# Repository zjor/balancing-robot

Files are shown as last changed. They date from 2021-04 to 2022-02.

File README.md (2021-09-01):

# Self-balancing robot

BLE-controlled self-balancing robot

- [Android BLE Joystick](/android/serial-ble-rc)
- [Arduino Code](/nano/twbr-nano)

## BOM

- Keywish BLE Nano x1
- A4988 Stepper Driver x2
- Stepper motor Nema17 x2
- MPU6050 x1

## References

- [Hackaday](https://hackaday.io/project/180126-self-balancing-robot-for-humans/)
- [Arduino Project](https://create.arduino.cc/projecthub/zjor/self-balancing-robot-with-arduino-nano-and-steppers-9bf019)
- Youtube (https://youtu.be/_VPTOirKccM)
- [Habr](https://habr.com/ru/post/575662/)

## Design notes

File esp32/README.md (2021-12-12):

# Self-balancing robot with ESP32 WROOM

## Pinout

### LED Wiring

- RED: GPIO32
- GREEN: GPIO33
- BLUE: GPIO25

### MPU9250 Wiring

- SCL: GPIO22
- SDA: GPIO21
- INT: GPIO19

### Motor 1 Wiring

- EN: GPIO15
- DIR: GPIO14
- STEP: GPIO12

### Motor 2 Wiring

- EN: GPIO16
- DIR: GPIO26
- STEP: GPIO27

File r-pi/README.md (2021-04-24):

# Balancing Robot

## Configuring headless Pi

1. Connect SD card to USB
2. `touch ssh` in the root directory
3. Create `wpa_supplicant.conf` file in the root directory with the following content

```
country=CZ
ctrl_interface=DIR=/var/run/wpa_supplicant GROUP=netdev
update_config=1
 
network={
    ssid="SSID"
    psk="PASSWORD"
}

```

4. Plug SD card to Pi and boot, after some time connect using
- `ssh pi@raspberrypi.local`

default password: raspberry

## Shutting down R Pi

`sudo shutdown -h now`

## Enable I2C

1. Install dependencies
```
sudo apt-get install -y python-smbus
sudo apt-get install -y i2c-tools
```

2. Enable I2C support
`sudo raspi-config`

3. Test connected devices
`sudo i2cdetect -y 1`

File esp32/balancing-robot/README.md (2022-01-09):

# Balancing Robot ESP32 WROOM

## Patching `SparkFun MPU-9250 Digital Motion Processing _DMP_ Arduino Library`

1. Go to `src/util/inv_mpu.h`
2. Add the following lines:
```C
#define min(X,Y) (((X) < (Y)) ? (X) : (Y))
#define max(X,Y) (((X) > (Y)) ? (X) : (Y))
```

## Notes

- `roll` is used for balancing

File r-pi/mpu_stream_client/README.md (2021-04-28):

# MPU Stream Client

- Renders a 3D object
- Pitch and roll are controlled by MPU data received via UPD stream

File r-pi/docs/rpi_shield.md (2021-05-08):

# R Pi Shield Spec

## PIN mapping

- MOT1_DIR -> GPIO_6 (31)
- MOT1_STEP -> GPIO_5 (29)
- MOT2_DIR -> GPIO_27 (13)
- MOT2_STEP -> GPIO_17 (11)
- MPU_SCL -> GPIO_3 (5)
- MPU_SDA -> GPIO_2 (3)

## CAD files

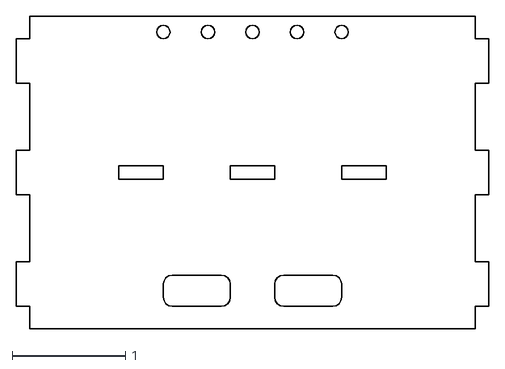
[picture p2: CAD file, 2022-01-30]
drawings/v3/bottom.dxf
4.17 x 2.76

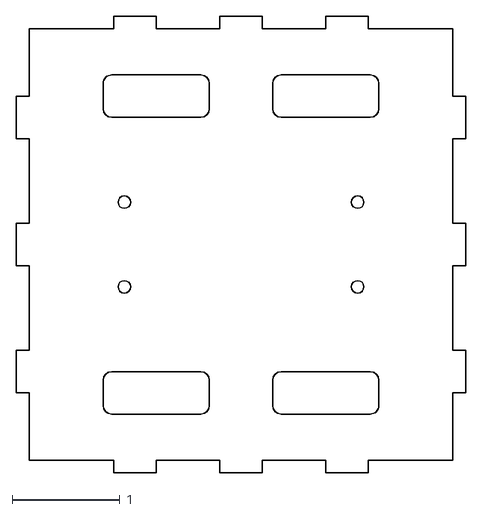
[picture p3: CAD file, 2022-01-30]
drawings/v3/middle.dxf
4.17 x 4.24

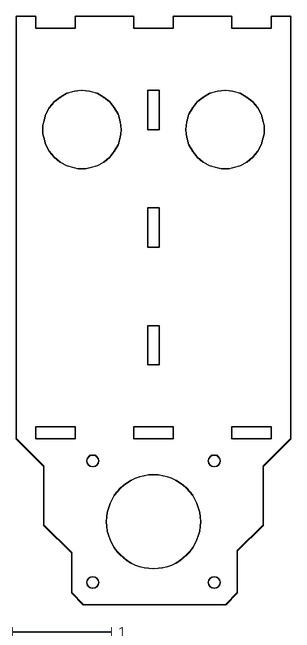
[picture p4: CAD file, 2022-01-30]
drawings/v3/side.dxf
2.76 x 5.91

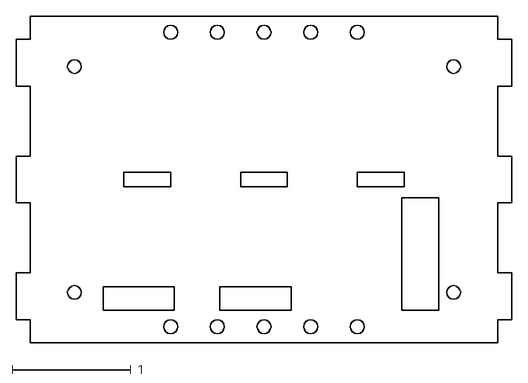
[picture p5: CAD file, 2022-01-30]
drawings/v3/top-mount.dxf
4.17 x 2.76

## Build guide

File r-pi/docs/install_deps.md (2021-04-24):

## Fixing "ImportError: No module named RPi"
- `sudo apt-get update`
- `sudo apt-get install python3-dev python3-rpi.gpio`

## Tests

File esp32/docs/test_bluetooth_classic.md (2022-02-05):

# Test Bluetooth classic sketch

ESP32 supports both BLE and Bluetooth classic protocol.
Bluetooth classic will be used to control the robot via serial protocol.

```
#include "BluetoothSerial.h"

BluetoothSerial btSerial;

void setup() {
  Serial.begin(115200);
  btSerial.begin("ESP32");
}

void loop() {
  if (btSerial.available()) {
    int c = btSerial.read();
    Serial.print((char) c);
  }
}
```

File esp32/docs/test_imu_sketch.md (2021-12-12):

# Test IMU MPU9250 Sketch

## platformio.ini

```
[env:esp32thing_plus]
monitor_speed = 115200
platform = espressif32
board = esp32doit-devkit-v1
framework = arduino
lib_deps = 
	sparkfun/SparkFun MPU-9250 Digital Motion Processing (DMP) Arduino Library@^1.0.0
```

## Source

```C++
#include <Arduino.h>
#include <SparkFunMPU9250-DMP.h>
#include <Wire.h>

#define R_LED_PIN 32
#define G_LED_PIN 33
#define B_LED_PIN 25

#define R_CH 0
#define G_CH 1
#define B_CH 2

#define INTERRUPT_PIN 19

MPU9250_DMP imu;

volatile bool dmpDataReady = false;

void measureCycles();

void dmpISR() {
  dmpDataReady = true;
}

void printRawAccel() {
  static long accel_counter = 0;
  static float avg_x = 0;
  static float avg_y = 0;
  static float avg_z = 0;

  avg_x += imu.ax;
  avg_y += imu.ay;
  avg_z += (imu.az - 16384);
  accel_counter++;

  if (accel_counter >= 100) {
    avg_x /= accel_counter;
    avg_y /= accel_counter;
    avg_z /= accel_counter;

    Serial.print(avg_x, 2);
    Serial.print("\t");
    Serial.print(avg_y, 2);
    Serial.print("\t");
    Serial.println(avg_z, 2);
    accel_counter = 0;
  }

}

float normalize_angle(float angle) {
  return (angle < 180) ? angle : angle - 360.0f;
}

void printIMUData(void) {
  float roll = normalize_angle(imu.roll);
  float pitch = normalize_angle(imu.pitch);
  float yaw = normalize_angle(imu.yaw);

  Serial.print("r:");
  Serial.print(roll);
  Serial.print("\tp:");  
  Serial.print(pitch);
  Serial.print("\ty:");
  Serial.println(yaw);
  
  ledcWrite(R_CH, map((int)fabs(roll), 0, 120, 0, 255));
  ledcWrite(G_CH, map((int)fabs(pitch), 0, 120, 0, 255));
  ledcWrite(B_CH, map((int)fabs(yaw), 0, 180, 0, 255));

  // float gyroX = imu.calcGyro(imu.gx);
  // float gyroY = imu.calcGyro(imu.gy);
  // float gyroZ = imu.calcGyro(imu.gz);

  // Serial.print(gyroX, 4); Serial.print("\t");
  // Serial.print(gyroY, 4); Serial.print("\t");
  // Serial.println(gyroZ, 4);
}

void setup() {
  Serial.begin(115200);

  pinMode(INTERRUPT_PIN, INPUT_PULLUP);

  if (imu.begin() != INV_SUCCESS) {
    while (1) {
      Serial.println("Failed to init IMU");
      delay(5000);
    }
  }

  imu.dmpBegin(DMP_FEATURE_6X_LP_QUAT | DMP_FEATURE_GYRO_CAL, 100);
  // -1030.98        -186.85 -1135.15
  // long bias[] = {-1030, -186, -1135};
  // imu.dmpSetAccelBias(bias); 

  // imu.setSampleRate(100);
  // imu.configureFifo(INV_XYZ_ACCEL);   
  imu.enableInterrupt();
  imu.setIntLevel(INT_ACTIVE_LOW);
  imu.setIntLatched(INT_LATCHED);

  attachInterrupt(INTERRUPT_PIN, dmpISR, FALLING);

  ledcAttachPin(R_LED_PIN, R_CH);
  ledcAttachPin(G_LED_PIN, G_CH);
  ledcAttachPin(B_LED_PIN, B_CH);

  ledcSetup(R_CH, 1000, 8);
  ledcSetup(G_CH, 1000, 8);
  ledcSetup(B_CH, 1000, 8);
}

void loop() {
  // if (imu.dataReady()) {
  //   imu.update(UPDATE_ACCEL);
  //   printRawAccel();
  // }
  if (dmpDataReady && imu.fifoAvailable()) {
    if (imu.dmpUpdateFifo() == INV_SUCCESS) {
      dmpDataReady = false;
      imu.computeEulerAngles();
      printIMUData();
    }
  }

  // measureCycles();
}

void measureCycles() {
  static unsigned long counter = 0;
  static unsigned long timestamp = 0;
  unsigned long now = millis();
  counter++;

  if (now - timestamp >= 1000) {
    Serial.println(counter);
    counter = 0;
    timestamp = now;
  }
}
```

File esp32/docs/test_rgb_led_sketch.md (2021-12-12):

# Test RGB LED sketch

```C++
#include <Arduino.h>

#define R_LED_PIN 32
#define G_LED_PIN 33
#define B_LED_PIN 25

#define R_CH 0
#define G_CH 1
#define B_CH 2

typedef struct RgbColor
{
    unsigned char r;
    unsigned char g;
    unsigned char b;
} RgbColor;

typedef struct HsvColor
{
    unsigned char h;
    unsigned char s;
    unsigned char v;
} HsvColor;

RgbColor HsvToRgb(HsvColor hsv)
{
    RgbColor rgb;
    unsigned char region, remainder, p, q, t;

    if (hsv.s == 0)
    {
        rgb.r = hsv.v;
        rgb.g = hsv.v;
        rgb.b = hsv.v;
        return rgb;
    }

    region = hsv.h / 43;
    remainder = (hsv.h - (region * 43)) * 6;

    p = (hsv.v * (255 - hsv.s)) >> 8;
    q = (hsv.v * (255 - ((hsv.s * remainder) >> 8))) >> 8;
    t = (hsv.v * (255 - ((hsv.s * (255 - remainder)) >> 8))) >> 8;

    switch (region)
    {
        case 0:
            rgb.r = hsv.v; rgb.g = t; rgb.b = p;
            break;
        case 1:
            rgb.r = q; rgb.g = hsv.v; rgb.b = p;
            break;
        case 2:
            rgb.r = p; rgb.g = hsv.v; rgb.b = t;
            break;
        case 3:
            rgb.r = p; rgb.g = q; rgb.b = hsv.v;
            break;
        case 4:
            rgb.r = t; rgb.g = p; rgb.b = hsv.v;
            break;
        default:
            rgb.r = hsv.v; rgb.g = p; rgb.b = q;
            break;
    }

    return rgb;
}

void setup() {
  Serial.begin(115200);
  ledcAttachPin(R_LED_PIN, R_CH);
  ledcAttachPin(G_LED_PIN, G_CH);
  ledcAttachPin(B_LED_PIN, B_CH);

  ledcSetup(R_CH, 1000, 8);
  ledcSetup(G_CH, 1000, 8);
  ledcSetup(B_CH, 1000, 8);

}
int i = 0;

void loop() {
  HsvColor hsv;
  hsv.h = i;
  hsv.s = 255;
  hsv.v = 255;

  RgbColor rgb = HsvToRgb(hsv);

  ledcWrite(R_CH, rgb.r);
  ledcWrite(G_CH, rgb.g);
  ledcWrite(B_CH, rgb.b);

  i++;
  if (i > 255) {
    i = 0;
  }
  delay(10);
}
```

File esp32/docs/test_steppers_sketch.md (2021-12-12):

# Test Steppers Sketch

```C++
#define MOT1_EN 15
#define MOT1_DIR 14
#define MOT1_STEP 12

#define MOT2_EN 16
#define MOT2_DIR 26
#define MOT2_STEP 27

void do_step(int step_pin) {
  digitalWrite(step_pin, HIGH);
  delayMicroseconds(4);
  digitalWrite(step_pin, LOW);  
}

void setup() {
  pinMode(MOT1_EN, OUTPUT);
  pinMode(MOT1_DIR, OUTPUT);
  pinMode(MOT1_STEP, OUTPUT);

  pinMode(MOT2_EN, OUTPUT);
  pinMode(MOT2_DIR, OUTPUT);
  pinMode(MOT2_STEP, OUTPUT);

  digitalWrite(MOT1_EN, LOW);
  digitalWrite(MOT2_EN, LOW);

  digitalWrite(MOT1_DIR, LOW);
  digitalWrite(MOT2_DIR, LOW);

  digitalWrite(MOT1_STEP, LOW);
  digitalWrite(MOT2_STEP, LOW);
  
}

void loop() {
  static int direction = HIGH;
  
  for (int i = 0; i < 200; i++) {
    do_step(MOT1_STEP);
    do_step(MOT2_STEP);
    delay(15);
  }
  direction = !direction;
  digitalWrite(MOT1_DIR, direction);
  digitalWrite(MOT2_DIR, direction);  
}
```

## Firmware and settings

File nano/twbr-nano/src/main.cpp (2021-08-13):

#include <Wire.h>
#include <Arduino.h>
#include "I2Cdev.h"
#include "MPU6050_6Axis_MotionApps20.h"

#include "pid/PID.h"

// PORTB, bit 1, PB1
#define MOT_A_STEP  9
#define MOT_A_DIR   8

// PORTD, bit 7, PD7
#define MOT_B_STEP  7
#define MOT_B_DIR   6

#define INTERRUPT_PIN 2

#define PPR   1600
// #define TICKS_PER_SECOND  40000 // 40kHz
#define TICKS_PER_SECOND  50000 // 50kHz
#define PULSE_WIDTH 1

#define MAX_ACCEL (200)
#define ANGLE_Kp  450.0
#define ANGLE_Kd  30.0
#define ANGLE_Ki  0.0

#define VELOCITY_Kp  0.007
#define VELOCITY_Kd  0.0
#define VELOCITY_Ki  0.0005

#define WARMUP_DELAY_US (5000000UL)

#define ANGLE_SET_POINT (2.0 * DEG_TO_RAD)

#define OUTPUT_READABLE_YAWPITCHROLL
// #define COUNT_LOOP
// #define LOGGING_ENABLED

#define NANO_BLE

/* BLE communication-related params */
#define MAX_PACKET_SIZE 96
#define DIVISOR 10000.0

char packet[MAX_PACKET_SIZE];
uint8_t packet_size = 0;

MPU6050 mpu;
bool dmpReady = false;
uint8_t mpuIntStatus;  
uint8_t fifoBuffer[64];

Quaternion q;           // [w, x, y, z]         quaternion container
VectorFloat gravity;    // [x, y, z]            gravity vector
float ypr[3];           // [yaw, pitch, roll]   yaw/pitch/roll container and gravity vector

volatile bool mpuInterrupt = false;     // indicates whether MPU interrupt pin has gone high
void dmpDataReady() {
    mpuInterrupt = true;
}

PID anglePID(ANGLE_Kp, ANGLE_Kd, ANGLE_Ki, ANGLE_SET_POINT);
PID velocityPID(VELOCITY_Kp, VELOCITY_Kd, VELOCITY_Ki, 0.0);

float pid_settings[6] = {
  ANGLE_Kp, ANGLE_Kd, ANGLE_Ki,
  VELOCITY_Kp, VELOCITY_Kd, VELOCITY_Ki
};

float joystick[2] = {0.0f, 0.0f};
float ref_velocity = 0.0f;
float ref_steering = 0.0f;
float steering = 0.0f;

volatile unsigned long currentTickLeft = 0UL;
volatile unsigned long currentTickRight = 0UL;
volatile unsigned long ticksPerPulseLeft = UINT64_MAX;
volatile unsigned long ticksPerPulseRight = UINT64_MAX;
volatile float accel = 0.0;
volatile float velocity = 0.0;

bool isBalancing = false;

float angle = 0.0;
float targetAngle = ANGLE_SET_POINT;

float targetVelocity = 0.0;

unsigned long lastUpdateMicros = 0;

void send_float_array(float *a, uint8_t size);
void parse_float_array(char *p, uint8_t p_size, float *dest);
void parse_settings(char *p, uint8_t p_size);
void parse_control(char *p, uint8_t p_size);
void handle_packet(char *p, uint8_t p_size);

void initMPU() {
  const int16_t accel_offset[3] = { -1262, -307, 1897 };
  const int16_t gyro_offset[3] = { 23, -41, 49 };

  Wire.begin();
  Wire.setClock(1000000UL);
  mpu.initialize();
  pinMode(INTERRUPT_PIN, INPUT);

  if (!mpu.testConnection()) {
    Serial.println(F("MPU6050 connection failed"));
    while(1) {}
  }

  mpu.dmpInitialize();

  mpu.setXGyroOffset(gyro_offset[0]);
  mpu.setYGyroOffset(gyro_offset[1]);
  mpu.setZGyroOffset(gyro_offset[2]);
  mpu.setXAccelOffset(accel_offset[0]);
  mpu.setYAccelOffset(accel_offset[1]);
  mpu.setZAccelOffset(accel_offset[2]);

  mpu.setDMPEnabled(true);
  attachInterrupt(digitalPinToInterrupt(INTERRUPT_PIN), dmpDataReady, RISING);
}

void setTimer1(int ocra) {  
  TCCR1A = 0; // set entire TCCR1A register to 0
  TCCR1B = 0; // same for TCCR1B
  TCNT1  = 0; // initialize counter value to 0  
  
  // ocra = 16MHz / prescaler / desired_f - 1
  OCR1A = ocra;
  TCCR1B |= (1 << WGM12); // turn on CTC mode
  TCCR1B |= (1 << CS11);  // set prescaler to 8  
  TIMSK1 |= (1 << OCIE1A);  // enable timer compare interrupt
}

void setTimers() {
  cli();
  // setTimer1(49); // 40kHz
  setTimer1(39); // 50kHz
  sei();
}

void initMotors() {
  pinMode(MOT_A_DIR, OUTPUT);
  pinMode(MOT_A_STEP, OUTPUT);
  pinMode(MOT_B_DIR, OUTPUT);
  pinMode(MOT_B_STEP, OUTPUT);
  digitalWrite(MOT_A_STEP, LOW);
  digitalWrite(MOT_B_STEP, LOW);
}

void log(unsigned long nowMicros) {  
  static unsigned long timestamp = micros();  
  if (nowMicros - timestamp < 10000 /* 100Hz */) {
    return;
  }
  Serial.print("a0:");
  Serial.print(targetAngle * RAD_TO_DEG, 4);
  Serial.print("\ta:");
  Serial.print(angle * RAD_TO_DEG, 4);
  Serial.print("\tv:");
  Serial.print(velocity, 4);
  Serial.print("\tu:");
  Serial.println(accel, 4);  
  timestamp = nowMicros;   
}

bool mpuUpdate() {
  if (mpuInterrupt && mpu.dmpGetCurrentFIFOPacket(fifoBuffer)) {
    mpu.dmpGetQuaternion(&q, fifoBuffer);
    mpu.dmpGetGravity(&gravity, &q);
    mpu.dmpGetYawPitchRoll(ypr, &q, &gravity);
    mpuInterrupt = false;
    return true;
  }
  return false;
}

unsigned long getTicksPerPulse(float velocity) {
  if (abs(velocity) < 1e-3) {
    // TODO: disable motor
    return UINT64_MAX;
  } else {
    return (uint64_t)(2.0 * PI * TICKS_PER_SECOND / (abs(velocity) * PPR)) - PULSE_WIDTH;
  }
}

void updateVelocity(unsigned long nowMicros) {
  // static unsigned long counter = 0;
  // static unsigned long sum = 0;

  static unsigned long timestamp = micros();
  if (nowMicros - timestamp < 100 /* 10kHz */) {
    return;
  }

  // sum += (nowMicros - timestamp);
  // counter++;
  // if (counter >= 1000) {
  //   Serial.println(((float)(sum)) / counter);
  //   counter = 0;
  //   sum = 0;
  // }

  float dt = ((float) (nowMicros - timestamp)) * 1e-6;
  velocity += accel * dt;
  
  float leftVelocity = velocity - steering;
  float rightVelocity = velocity + steering;
  ticksPerPulseLeft = getTicksPerPulse(leftVelocity);
  ticksPerPulseRight = getTicksPerPulse(rightVelocity);
  
  if (leftVelocity > 0) {
    digitalWrite(MOT_A_DIR, HIGH);    
  } else {
    digitalWrite(MOT_A_DIR, LOW);
  }

  if (rightVelocity > 0) {
    digitalWrite(MOT_B_DIR, LOW);  
  } else {
    digitalWrite(MOT_B_DIR, HIGH);  
  }

  timestamp = nowMicros;
}

void updateControl(unsigned long nowMicros) {
  /* Wait until IMU filter will settle */
  if (nowMicros < WARMUP_DELAY_US) {
    return;
  }

  static unsigned long timestamp = micros();
  if (nowMicros - timestamp < 1000 /* 1kHz */) {
    return;
  }
  if (!mpuUpdate()) {
    return;
  }
  angle = ypr[1];

  float dt = ((float) (nowMicros - timestamp)) * 1e-6;

  if (abs(angle - targetAngle) < PI / 18) {
    isBalancing = true;
  }

  if (abs(angle - targetAngle) > PI / 4) {
    isBalancing = false;
    accel = 0.0;
    velocity = 0.0;    
  }

  if (!isBalancing) {
    return;
  }
  targetAngle = -velocityPID.getControl(velocity, dt);
  anglePID.setTarget(targetAngle);

  accel = anglePID.getControl(angle, dt);
  accel = constrain(accel, -MAX_ACCEL, MAX_ACCEL);

  timestamp = nowMicros;
}

void setup() {
  Serial.begin(115200);
  #ifdef NANO_BLE
    Serial.print("AT+BAUD=4\r\n");
  #endif
  initMPU();
  setTimers();
  initMotors();
}

void loop() {  
  unsigned long now = micros();
  updateVelocity(now);
  updateControl(now);
  #ifdef LOGGING_ENABLED
    log(now);
  #endif

  #ifdef COUNT_LOOP
    static unsigned long last_ts = micros();
    static unsigned long  counter = 0;

    counter++;
    if (now - last_ts >= 1000000) {
      Serial.println(counter);
      counter = 0;
      last_ts = now;
    }
  #endif

  while (Serial.available()) {
    int c = Serial.read();
    if (c == '\n') {
        continue;
    } else if (c == '\r') {
        handle_packet(packet, packet_size);
        packet_size = 0;
    } else {
        packet[packet_size++] = (uint8_t) c;
    }
  }
  static const float a = 0.99;
  targetVelocity = a * targetVelocity + (1.0 - a) * ref_velocity;
  velocityPID.setTarget(targetVelocity);

  steering = a * steering + (1.0 - a) * ref_steering;
}

/**
 * Stepper control interrupt handler
 */
ISR(TIMER1_COMPA_vect) {
  if (currentTickLeft >= ticksPerPulseLeft) {
    currentTickLeft = 0;
  }

  if (currentTickLeft == 0) {
    PORTD |= _BV(PD7); // digitalWrite(MOT_B_STEP, HIGH);
  } else if (currentTickLeft == PULSE_WIDTH) {
    PORTD &= ~_BV(PD7); // digitalWrite(MOT_B_STEP, LOW);
  }
  
  currentTickLeft++;

  if (currentTickRight >= ticksPerPulseRight) {
    currentTickRight = 0;
  }

  if (currentTickRight == 0) {
    PORTB |= _BV(PB1); // digitalWrite(MOT_A_STEP, HIGH);
  } else if (currentTickRight == PULSE_WIDTH) {
    PORTB &= ~_BV(PB1); // digitalWrite(MOT_A_STEP, LOW);    
  }
  
  currentTickRight++;
}

void send_float_array(float *a, uint8_t size) {
    for (int i = 0; i < size; i++) {
        Serial.print((long)(a[i] * DIVISOR));
        if (i < size - 1) {
            Serial.print(';');
        }
    }
    Serial.print("\r\n");
}

void parse_float_array(char *p, uint8_t p_size, float *dest) {
    char buf[16];
    long value;
    uint8_t buf_size = 0;
    uint8_t index = 0;
    for (uint8_t i = 0; i < p_size; i++) {
        if ((p[i] >= '0' && p[i] <= '9') || p[i] == '+' || p[i] == '-') {
            buf[buf_size++] = p[i];
        } else if (p[i] == ';') {
            buf[buf_size] = '\0';
            buf_size = 0;
            value = atol(buf);
            dest[index++] = ((float)value) / DIVISOR;
        }
    }
    buf[buf_size] = '\0';
    value = atol(buf);
    dest[index] = ((float)value) / DIVISOR;
}

void parse_settings(char *p, uint8_t p_size) {
    parse_float_array(p, p_size, pid_settings);
    anglePID.setSettings(pid_settings[0], pid_settings[1], pid_settings[2]);
    velocityPID.setSettings(pid_settings[3], pid_settings[4], pid_settings[5]);
}

void parse_control(char *p, uint8_t p_size) {
    parse_float_array(p, p_size, joystick);
    ref_velocity = joystick[0];
    ref_steering = joystick[1];
}

void handle_packet(char *p, uint8_t p_size) {
    switch (p[0]) {
        case 'r':
            send_float_array(pid_settings, 6);
            break;
        case 's':
            parse_settings(&p[1], p_size - 1);
            send_float_array(pid_settings, 6);
            break;
        case 'c':
            parse_control(&p[1], p_size - 1);
            // send_float_array(joystick, 2);
            break;
    }
}

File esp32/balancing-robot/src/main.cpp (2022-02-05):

/**

 * # LED Wiring

 * - RED: GPIO32
 * - GREEN: GPIO33
 * - BLUE: GPIO25
 *
 * 
 * # MPU9250 Wiring
 * 
 * - SCL: GPIO22
 * - SDA: GPIO21
 * - INT: GPIO19
 * 
 * 
 * # Motor 1 Wiring
 * 
 * - EN: GPIO15
 * - DIR: GPIO14
 * - STEP: GPIO12
 * 
 * 
 * # Motor 2 Wiring
 * 
 * - EN: GPIO16
 * - DIR: GPIO26
 * - STEP: GPIO27
 * 
 * 
 * @author Sergey Royz (zjor.se@gmail.com) 
 * @version 0.1
 * @date 2021-12-28
 * 
 * 
 */
#include <Arduino.h>
#include <Wire.h>
#include <SparkFunMPU9250-DMP.h>

#include "pid/PID.h"
#include "stepper/Stepper.h"
#include "indicator/Indicator.h"

#define PIN_IMU_SCL 22
#define PIN_IMU_SDA 21
#define PIN_IMU_INT 19

#define PIN_MOTOR_RIGHT_EN    15
#define PIN_MOTOR_RIGHT_DIR   14
#define PIN_MOTOR_RIGHT_STEP  12

#define PIN_MOTOR_LEFT_EN    16
#define PIN_MOTOR_LEFT_DIR   26
#define PIN_MOTOR_LEFT_STEP  27

#define PPR       1600

#define CPU_FREQ_MHZ  240
#define CPU_FREQ_DIVIDER  120
#define TICKS_PER_SECOND (200000 * (CPU_FREQ_MHZ / CPU_FREQ_DIVIDER))
#define PULSE_WIDTH      1

#define MAX_ACCEL (200)
#define ANGLE_Kp  800.0
#define ANGLE_Kd  60.0
#define ANGLE_Ki  0.0

#define VELOCITY_Kp  0.005
#define VELOCITY_Kd  0.0
#define VELOCITY_Ki  0.000002

#define WARMUP_DELAY_US (7000000UL)

#define ANGLE_SET_POINT (1.5 * DEG_TO_RAD)

// #define LOG_IMU
// #define LOG_ENABLED

void initTimerInterrupt();

float normalizeAngle(float);

void updateVelocity(unsigned long);
void updateControl(unsigned long);
void log(unsigned long);

Indicator indicator;

Stepper leftStepper(PIN_MOTOR_LEFT_EN, PIN_MOTOR_LEFT_DIR, PIN_MOTOR_LEFT_STEP, TICKS_PER_SECOND, PPR, PULSE_WIDTH);
Stepper rightStepper(PIN_MOTOR_RIGHT_EN, PIN_MOTOR_RIGHT_DIR, PIN_MOTOR_RIGHT_STEP, TICKS_PER_SECOND, PPR, PULSE_WIDTH);

MPU9250_DMP imu;
volatile bool dmpDataReady = false;
float roll, pitch, yaw;

void dmpISR() {
  dmpDataReady = true;
}

void initIMU() {
  pinMode(PIN_IMU_INT, INPUT_PULLUP);

  if (imu.begin() != INV_SUCCESS) {
    while (1) {
      Serial.println("Failed to init IMU");
      delay(5000);
    }
  }

  imu.dmpBegin(DMP_FEATURE_6X_LP_QUAT | DMP_FEATURE_GYRO_CAL, 100);
  imu.enableInterrupt();
  imu.setIntLevel(INT_ACTIVE_LOW);
  imu.setIntLatched(INT_LATCHED);  

  attachInterrupt(PIN_IMU_INT, dmpISR, FALLING);
}

bool readIMU() {
  if (dmpDataReady && imu.fifoAvailable()) {
    if (imu.dmpUpdateFifo() == INV_SUCCESS) {
      dmpDataReady = false;
      imu.computeEulerAngles();
      roll = imu.roll;
      pitch = imu.pitch;
      yaw = imu.yaw;
      return true;
    }
  }
  return false;
}

void logIMU() {
  #ifdef LOG_IMU
  static unsigned long lastTimestamp = millis();
  unsigned long now = millis();
  if (now - lastTimestamp > 50) {
    // Serial.print("r:"); Serial.print(roll); Serial.print("\t");
    // Serial.print("p:"); Serial.print(pitch); Serial.print("\t");
    // Serial.print("y:"); Serial.println(yaw);
    Serial.print("r:");Serial.print(roll);Serial.print("\t");
    Serial.println(normalizeAngle(roll));
    lastTimestamp = now;
  }
  #endif
}

PID anglePID(ANGLE_Kp, ANGLE_Kd, ANGLE_Ki, ANGLE_SET_POINT);
PID velocityPID(VELOCITY_Kp, VELOCITY_Kd, VELOCITY_Ki, 0.0);
bool isBalancing = false;

float accel = 0.0f;
float velocity = 0.0f; 
float angle = 0.0f;
float targetAngle = ANGLE_SET_POINT;

hw_timer_t * timer = NULL;

void IRAM_ATTR onTimer() {
  leftStepper.tick();
  rightStepper.tick();
}

float normalizeAngle(float value) { 
  return ((value < 180) ? value : value - 360.0f) * DEG_TO_RAD;
}

void setup(void) {
  setCpuFrequencyMhz(CPU_FREQ_MHZ);

  Serial.begin(115200);
  Wire.begin();
  Wire.setClock(1000000UL);

  initTimerInterrupt();

  initIMU();

  leftStepper.init();
  rightStepper.init();
  leftStepper.setEnabled(true);
  rightStepper.setEnabled(true);
  
  indicator.init();
  indicator.setColor(0xFF0000);
}

void loop() {
  unsigned long nowMicros = micros();
  updateVelocity(nowMicros);
  updateControl(nowMicros);
  logIMU();
  #ifdef LOG_ENABLED
  log(nowMicros);
  #endif
}

void initTimerInterrupt() {
  // 80MHz / 80 / 5 = 200kHz  
  timer = timerBegin(0 /* timer ID */, CPU_FREQ_DIVIDER /* CPU frequency divider */, true /* count up */);
  timerAttachInterrupt(timer, &onTimer, true /* edge */);
  timerAlarmWrite(timer, 5 /* int at counter value */, true /* reload counter */);
  timerAlarmEnable(timer);
}

void updateVelocity(unsigned long nowMicros) {
  static unsigned long timestamp = micros();
  if (nowMicros - timestamp < 50 /* 20 kHz */) {
    return;
  }

  float dt = ((float) (nowMicros - timestamp)) * 1e-6;
  velocity += accel * dt;

  leftStepper.setVelocity(velocity);
  rightStepper.setVelocity(-velocity);
  
  timestamp = nowMicros;
}

void setBalancing(bool balancing) {
  if (isBalancing != balancing) {
    isBalancing = balancing;
    #ifdef LOG_ENABLED
    Serial.print("IsBalancing: ");
    Serial.println(isBalancing);
    #endif
    indicator.setColor(isBalancing ? 0x0000FF : 0x00FF00);
  }  
}

void setIMUWarmUpElapsed() {
  static bool invoked = false;
  if (!invoked) {
    invoked = true;
    indicator.setColor(0x00FF00);
    #ifdef LOG_ENABLED
    Serial.println("IMU Warm Up timeout elapsed");
    #endif
  }
}

void updateControl(unsigned long nowMicros) {
  static unsigned long timestamp = micros();
  if (nowMicros - timestamp < 1000 /* 1kHz*/) {
    return;
  }

  if (!readIMU()) {
    return;
  }

  /* Wait until IMU filter will settle */
  if (nowMicros < WARMUP_DELAY_US) {    
    return;
  } 
  setIMUWarmUpElapsed();

  angle = normalizeAngle(roll);

  float dt = ((float) (nowMicros - timestamp)) * 1e-6;

  if (abs(angle - targetAngle) < PI / 18) {
    setBalancing(true);
  }

  if (abs(angle - targetAngle) > PI / 4) {
    setBalancing(false);
    accel = 0.0;
    velocity = 0.0;    
  }

  if (!isBalancing) {
    return;
  }
  targetAngle = -velocityPID.getControl(velocity, dt);
  anglePID.setTarget(targetAngle);

  accel = anglePID.getControl(angle, dt);
  accel = constrain(accel, -MAX_ACCEL, MAX_ACCEL);

  timestamp = nowMicros;
}

void log(unsigned long nowMicros) {  
  static unsigned long timestamp = micros();  
  if (nowMicros - timestamp < 100000 /* 10Hz */) {
    return;
  }
  Serial.print("roll:");
  Serial.print(roll, 2);
  Serial.print("\t");

  Serial.print("a0:");
  Serial.print(targetAngle * RAD_TO_DEG, 4);
  Serial.print("\ta:");
  Serial.print(angle * RAD_TO_DEG, 4);
  Serial.print("\tv:");
  Serial.print(velocity, 4);
  Serial.print("\tu:");
  Serial.println(accel, 4);  
  timestamp = nowMicros;   
}

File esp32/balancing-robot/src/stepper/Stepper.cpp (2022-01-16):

#include <Arduino.h>

#include "Stepper.h"

int getTicksPerPulse(float velocity, int32_t ticksPerSecond, uint32_t pulsesPerRevolution, uint32_t pulseWidth) {
  if (abs(velocity) < 1e-3) {
    return UINT32_MAX;
  } else {
    return (uint32_t)(TWO_PI * ticksPerSecond / (abs(velocity) * pulsesPerRevolution)) - pulseWidth;
  }  
}

Stepper::Stepper(int enablePin, int dirPin, int stepPin, uint32_t ticksPerSecond, uint32_t pulsesPerRevolution, uint32_t pulseWidth) {
  this->enablePin = enablePin;
  this->dirPin = dirPin;
  this->stepPin = stepPin;
  this->ticksPerSecond = ticksPerSecond;
  this->pulsesPerRevolution = pulsesPerRevolution;
  this->pulseWidth = pulseWidth;  
}

void Stepper::init() {
  pinMode(enablePin, OUTPUT);
  pinMode(dirPin, OUTPUT);
  pinMode(stepPin, OUTPUT);
  digitalWrite(stepPin, LOW);
  
  this->currentTick = 0;
}

void Stepper::setEnabled(bool enabled) {
  digitalWrite(enablePin, enabled ? LOW : HIGH);
}

void Stepper::setVelocity(float velocity) {
  ticksPerPulse = getTicksPerPulse(velocity, ticksPerSecond, pulsesPerRevolution, pulseWidth);
  digitalWrite(dirPin, velocity > 0 ? HIGH : LOW);
}

void Stepper::tick() {
  if (currentTick >= ticksPerPulse) {
    currentTick = 0;
  }
  if (currentTick == 0) {
    digitalWrite(stepPin, HIGH);
  } else if (currentTick == pulseWidth) {    
    digitalWrite(stepPin, LOW);
  }
  currentTick++; 
}

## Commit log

2021-04-24 roll pitch
2021-04-24 stepper test
2021-04-25 control velocity with an angle
2021-05-13 esp32 code added
2021-05-16 mpu calibration
2021-05-16 tuning pid
2021-05-22 gyro angles
2021-05-22 imu lib
2021-06-06 switched to 100kHz stepper control
2021-06-09 lower stepper frequency
2021-06-09 velocity fix loop
2021-07-05 used int pin
2021-08-07 pid settings fragment
2021-08-09 configure PID via BLE
2021-08-10 send joystick data to the device
2021-08-11 velocity control with BLE
2021-08-11 steering added
2021-09-01 velocity resolution
2021-12-12 led test sketch added
2021-12-12 imu test sketch added
2021-12-28 esp32: wip
2021-12-29 reading IMU
2022-01-09 enbling motors
2022-01-09 update velocity
2022-01-09 stepper: wip
2022-01-10 stepper library: wip
2022-01-12 stepper library: impl
2022-01-12 velocity fix
